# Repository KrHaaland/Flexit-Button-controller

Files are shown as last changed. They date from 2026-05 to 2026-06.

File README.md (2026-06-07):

# Flexit-Button-controller

ESP32-C5 button panel for the **Flexit Tradition-S** ventilation unit. Replaces or parallels the original 5-button control panel with an isolated emulator that adds **Wi-Fi (2.4 GHz + 5 GHz)** and **MQTT** for smart-home integration.

The ESP32-C5 is currently one of the few cheap ESP modules with dual-band Wi-Fi 6, which lets the panel live on either band depending on your home network and signal coverage.

## What it does

The board exposes 5 channels, each mirroring one button + indicator LED on the original Flexit Tradition-S panel:

- **5 button outputs** drive AQY212S solid-state opto-couplers in parallel with on-board tactile switches. A short pulse on a channel looks electrically identical to a finger press, in galvanic isolation from the Flexit unit.
- **5 LED inputs** read the indicator-LED state back from the panel net.

You get three ways to interact with the panel:

1. The physical tactile buttons on the PCB (works without firmware).
2. A self-served web UI (Wi-Fi setup, manual trigger, live LED dots, pulse tuning, MQTT setup).
3. MQTT — subscribe to LED state changes, publish to fire buttons.

## Hardware

- **Module:** ESP32-C5-Mini (USB-C, dual-band Wi-Fi 6, 4 MB flash, no PSRAM)
- **Isolation:** 5x AQY212S solid-state relays (LED-driven MOSFET output, ~3 ms switching)
- **Connector to Flexit:** Micro-MaTch 2x6 (J1), carrying 5 button signals + 5 LED signals + 5 V supply + GND, mating with the cable on the back of the original Flexit panel.
- **PCB:** KiCad files under [`PCB/`](PCB/) (Gerbers/BOM/positions for the fab in [`PCB/production/`](PCB/production/)).

### Pin mapping (set in `FW/ESP32-C5-Flexit/src/main.cpp`)

| Channel | Trigger out | LED in |
|---:|:---:|:---:|
| 1 | IO4 | IO5 |
| 2 | IO3 | IO6 |
| 3 | IO2 | IO7 |
| 4 | IO1 | IO8 |
| 5 | IO0 | IO9 |

Trigger outputs idle LOW and pulse HIGH for ~300 ms (configurable from the UI) to emulate a press. LED inputs are read with `INPUT_PULLDOWN`; the Flexit drives them HIGH when an indicator is lit.

## Build & flash

Requires [PlatformIO](https://platformio.org/) (`pip install platformio` or the VSCode extension).

```bash
cd FW/ESP32-C5-Flexit
pio run                       # compile
pio run -t upload             # flash via USB-C
pio device monitor -b 115200  # serial log
```

The C5 enumerates as `/dev/ttyACM*` (built-in USB Serial JTAG, no driver needed).

## First-time setup

1. Power the ESP32-C5 over USB-C, or via the J1 connector once mounted.
2. With no saved Wi-Fi, the board comes up as an access point:
   - SSID: `Flexit-Setup`
   - Password: `fibonacci` (default; the Wi-Fi form lets you set a custom one if you don't want the documented value).
3. Join that AP and open <http://192.168.4.1/> (also reachable as `http://flexit.local/` via mDNS).
4. In the **Wi-Fi** section, enter your home SSID + password and click *Save & reboot*. You can optionally set a custom AP fallback password in the same form — it persists in NVS. The board joins your network and is then reachable on its STA IP or via `flexit.local`.

Wi-Fi credentials and the AP-password override are stored in NVS and survive a reflash. *Forget & reboot to AP* wipes the Wi-Fi creds but keeps the AP password override.

If the home network is briefly unreachable at boot, the board lands in AP mode but periodically retries (every 5 min) so a transient router outage doesn't strand it.

## Web interface

| Section | What it does |
|---|---|
| **Knapper** | 5 trigger buttons + 5 live LED indicators (polled every 400 ms). |
| **Pulse duration** | Length of the simulated button press (20–2000 ms, default 300 ms). Useful if a Flexit function requires a long-press. |
| **MQTT** | Broker host/port, optional user/password, base topic, heartbeat republish interval, live connection status, MAC-derived client ID. |
| **Wi-Fi** | SSID + password, *Save & reboot* into STA, *Forget* clears creds. Banner at top shows current STA/AP state, RSSI, IP. |

Everything except Wi-Fi changes applies live without reboot.

## MQTT

When the board is in STA mode (joined to your Wi-Fi) and a broker host is configured, it connects to the broker and stays connected with auto-reconnect and a Last Will. With base topic `flexit` (default — configurable in the UI):

| Topic | Direction | Payload | Notes |
|---|---|---|---|
| `flexit/led/1..5/state` | publish | `ON` / `OFF` | Retained. Sent on every transition; also republished periodically if heartbeat > 0. |
| `flexit/sw/1..5/trigger` | subscribe | any (optional `<ms>`) | Any payload triggers a pulse on that channel. A numeric payload overrides the configured pulse duration for that single trigger. |
| `flexit/status` | publish | `online` / `offline` | LWT, retained. |

Client ID is `flexit-<MAC>` (12 hex chars from the chip's eFuse MAC) — globally unique per ESP32. Use it in your broker's ACL.

### Home Assistant example

```yaml
mqtt:
  binary_sensor:
    - name: "Flexit LED 1"
      state_topic: "flexit/led/1/state"
      payload_on: "ON"
      payload_off: "OFF"
    # ... repeat for 2..5
  button:
    - name: "Flexit button 1"
      command_topic: "flexit/sw/1/trigger"
    # ... repeat for 2..5
```

## Firmware updates (OTA)

Once the device is on your Wi-Fi (STA mode), you don't need USB again — there are two ways to push a new build:

### Web upload

1. Build locally: `cd FW/ESP32-C5-Flexit && pio run`. The artifact is `.pio/build/esp32-c5-devkitc1-n4/firmware.bin`.
2. Open the device's web UI (`http://flexit.local/` or its STA IP).
3. Scroll to the **Firmware** section. The current version, build timestamp and free slot space are shown.
4. Pick the new `firmware.bin`, click **Upload & reboot**. The progress bar tracks the upload, then the board reboots into the new image. The page auto-reloads after ~8 s.

### PlatformIO push

```bash
cd FW/ESP32-C5-Flexit
pio run -e esp32-c5-devkitc1-n4-ota -t upload
```

This uses the espota protocol over mDNS at `flexit.local:3232`.

### Partition layout

Switched from the Arduino default (`default.csv`, 1.25 MB per app slot) to `min_spiffs.csv` (1.875 MB per slot, two slots, plus 128 KB SPIFFS). NVS stays at offset `0x9000` so saved Wi-Fi / MQTT / pulse settings survive the migration when you flash the OTA-enabled image for the first time.

### Robustness

The HTTP OTA path is hardened against the common failure modes:

- The 5 button-trigger pins are forced LOW at the start of every upload, and `/trigger` + MQTT-fired triggers are ignored during the upload — a press in flight can't keep the opto-coupler latched through the multi-second multipart parse.
- Idle timeout (10 s) and total timeout (120 s) abort slow-loris uploads.
- A sticky abort flag short-circuits the rest of the upload as soon as `Update.begin`, a short write, or `Update.end` reports an error — no point in streaming 1 MB just to fail at the end.
- MQTT publishes `offline` retained to `<base>/status` and disconnects gracefully before the reboot, so subscribers see the flap immediately instead of waiting out the 30 s keepalive.
- Wi-Fi disconnect + `server.close()` + an 800 ms settle before `ESP.restart()` give the TCP FIN and the HTTP 200 response enough time to flush on a marginal link.
- A Wi-Fi event handler re-binds mDNS and ArduinoOTA whenever the STA interface gets a new IP, so wireless reflash keeps working after a router reboot or AP roam.

### Security model

There's **no authentication** on either OTA path or on the other config endpoints. The assumption is that your Wi-Fi LAN is trusted (this is a home device behind your router, not on the open internet). Anyone with route to the device on TCP 80 or 3232 can re-flash it.

The AP fallback PSK is `fibonacci` by default — yes, the same one this README mentions, on purpose. The Wi-Fi form lets you override it per device if you'd rather not advertise it in the source. Override is persisted in NVS.

If you need stricter controls (HTTP Basic auth on `/update`, an ArduinoOTA password, signed firmware images, broker ACLs, VLANs), open an issue.

## Repo layout

```
.
├── FW/ESP32-C5-Flexit/      PlatformIO project (Arduino framework)
│   ├── src/main.cpp         Firmware
│   └── src/index_html.h     Embedded web UI (single page)
├── PCB/                     KiCad schematic + PCB design
│   └── production/          Gerbers, BOM, positions for fab
└── knappepanel_flexit.kicad_pro
```

## Notes & quirks

- The board has 5 on-board tactile switches in parallel with the opto outputs, and 5 indicator LEDs on the LED nets, so it doubles as a stand-alone bench panel.
- ESP32-C5 boot prints `MSPI Timing: Failed to allocate dummy cacheline for PSRAM memory barrier!` — harmless, the C5-Mini has no PSRAM but the SDK looks for it.
- Verified against a Flexit Tradition-S. Other Flexit models with a different button matrix or LED drive scheme may need pin or polarity changes (see `LED_ACTIVE_HIGH` in `src/main.cpp`).

## License

No license set yet — treat as "all rights reserved" until one is added. Open an issue if you'd like a specific one (MIT / Apache-2.0 / CC-BY-SA for the hardware, etc.).

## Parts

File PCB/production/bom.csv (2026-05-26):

Designator | Footprint | Quantity | Value | LCSC Part #
C1, C2 | 0805 | 2 | 10uF
D1, D2, D3, D4, D5 | 1206 | 5 | LED
J1 | Micromatch_2x6 | 1 | MicroMatch_2x6
R1, R2, R3, R4, R5 | 0805 | 5 | R
SW1, SW2, SW3, SW4, SW5 | Tactile SW 6x6mm | 5 | Tactile SW 6x6mm | C5127964
TP1, TP2 | TestPoint_Pad_1.5x1.5mm | 2 | TestPoint
U1, U2, U3, U4, U5 | AQY212S | 5 | AQY212S
U7 | ESP32-C5Mini | 1 | ~

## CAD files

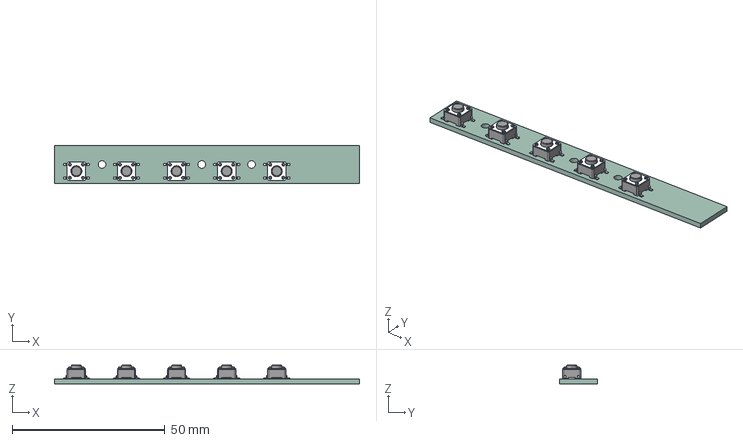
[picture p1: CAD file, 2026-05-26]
.step
100.0 x 12.5 x 6.10 mm
knappepanel_flexit_PCB

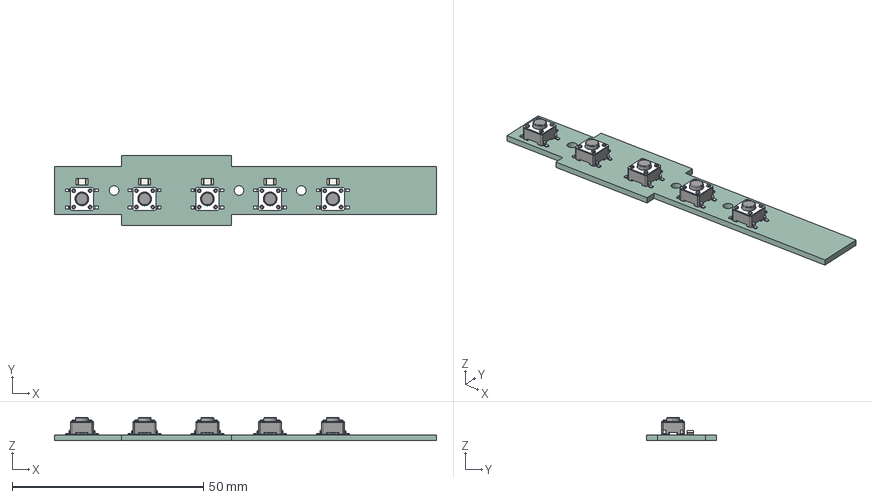
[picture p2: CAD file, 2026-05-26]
PCB/knappepanel.step
100.0 x 18.2 x 6.10 mm
LED_1206_3216Metric x 5
knappepanel_flexit_PCB

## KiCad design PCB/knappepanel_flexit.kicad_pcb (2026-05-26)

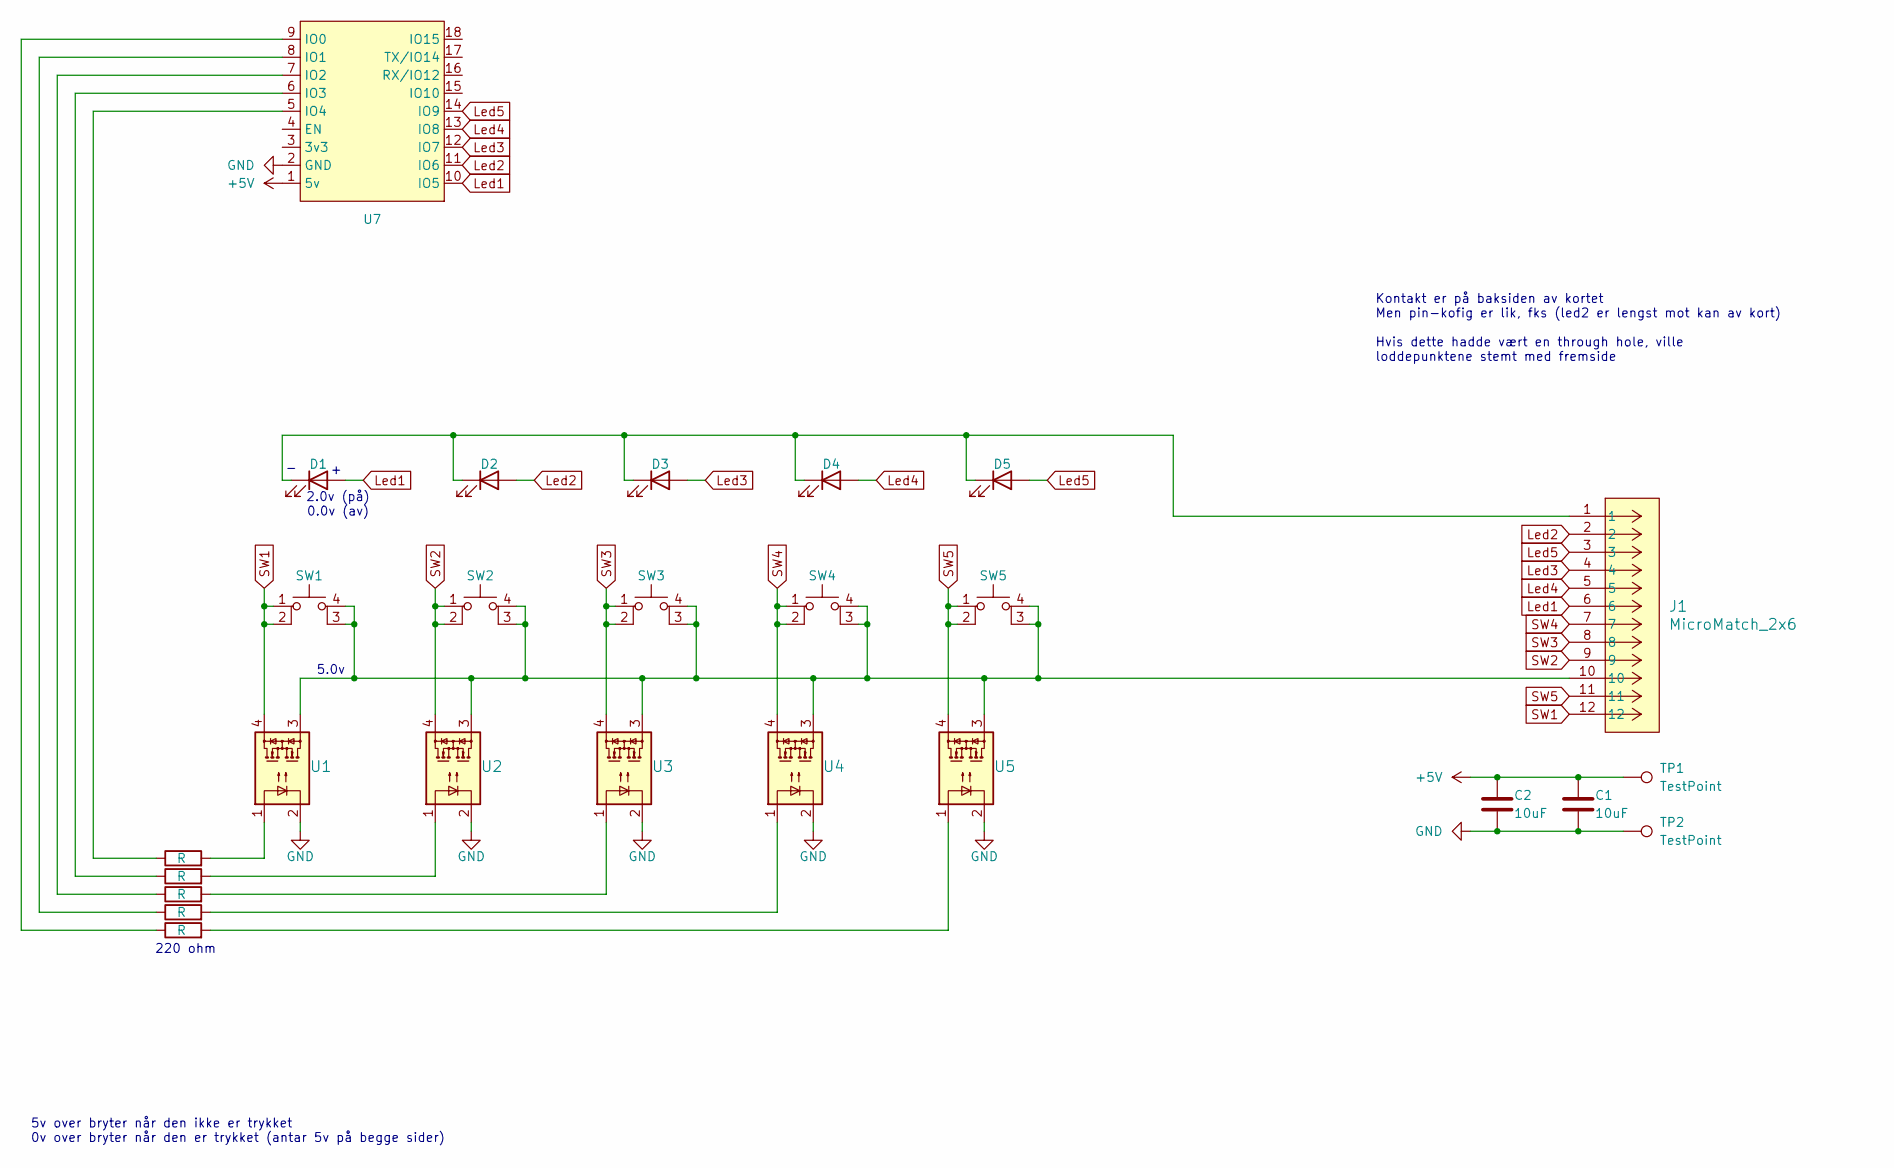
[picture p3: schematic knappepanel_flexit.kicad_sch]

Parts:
C1, C2: 10uF; C_0805_2012Metric
D1, D2, D3, D4, D5: LED; LED_1206_3216Metric
J1: MicroMatch_2x6; Micromatch_2x6
R1, R2, R3, R4, R5: R; R_0805_2012Metric
SW1, SW2, SW3, SW4, SW5: Tactile SW 6x6mm; LCSC Part C5127964
TP1, TP2: TestPoint; TestPoint_Pad_1.5x1.5mm
U1, U2, U3, U4, U5: AQY212S
U7: ESP32-C5Mini

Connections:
+5V: C1.1, C2.1, TP1.1 (1_1), U7.1 (5v)
GND: C1.2, C2.2, TP2.1 (1_1), U1.2, U2.2, U3.2, U4.2, U5.2, U7.2 (GND)
Led1: D1.2 (A), J1.6, U7.10 (IO5)
Led2: D2.2 (A), J1.2, U7.11 (IO6)
Led3: D3.2 (A), J1.4, U7.12 (IO7)
Led4: D4.2 (A), J1.5, U7.13 (IO8)
Led5: D5.2 (A), J1.3, U7.14 (IO9)
unnamed: D1.1 (K), D2.1 (K), D3.1 (K), D4.1 (K), D5.1 (K), J1.1
unnamed: J1.10, SW1.3, SW1.4, SW2.3, SW2.4, SW3.3, SW3.4, SW4.3, SW4.4, SW5.3, SW5.4, U1.3, U2.3, U3.3, U4.3, U5.3
unnamed: R1.2, U1.1
unnamed: R2.2, U2.1
unnamed: R3.2, U3.1
unnamed: R4.2, U4.1
unnamed: R5.2, U5.1
unnamed: R5.1, U7.9 (IO0)
unnamed: R4.1, U7.8 (IO1)
unnamed: R3.1, U7.7 (IO2)
unnamed: R2.1, U7.6 (IO3)
unnamed: R1.1, U7.5 (IO4)
SW1: J1.12, SW1.1, SW1.2, U1.4
SW2: J1.9, SW2.1, SW2.2, U2.4
SW3: J1.8, SW3.1, SW3.2, U3.4
SW4: J1.7, SW4.1, SW4.2, U4.4
SW5: J1.11, SW5.1, SW5.2, U5.4

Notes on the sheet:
5v over bryter når den ikke er trykket 0v over bryter når den er trykket (antar 5v på begge sider)
5.0v
2.0v (på) 0.0v (av)
Kontakt er på baksiden av kortet Men pin-kofig er lik, fks (led2 er lengst mot kan av kort) Hvis dette hadde vært en through hole, ville loddepunktene stemt med fremside
220 ohm

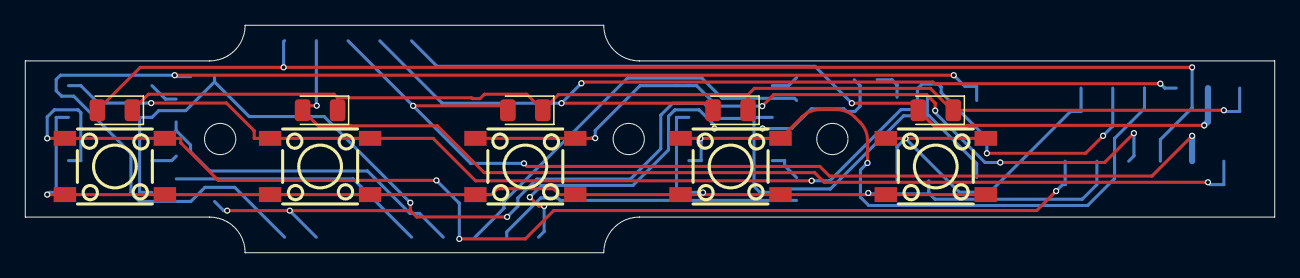
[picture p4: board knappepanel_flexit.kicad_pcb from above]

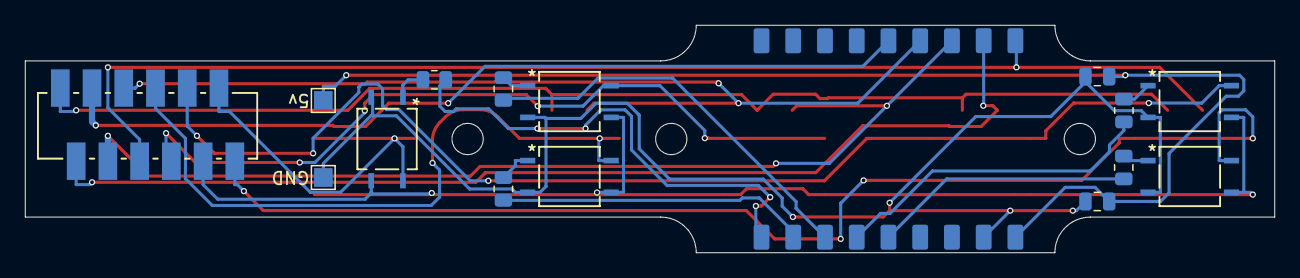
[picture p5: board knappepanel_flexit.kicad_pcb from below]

Board: 2 copper layers, 100.0 x 18.2 mm, 26 parts (16 on the bottom side), 24 nets.

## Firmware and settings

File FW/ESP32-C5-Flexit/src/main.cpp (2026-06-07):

#include <Arduino.h>
#include <WiFi.h>
#include <WebServer.h>
#include <ESPmDNS.h>
#include <Preferences.h>
#include <PubSubClient.h>
#include <Update.h>
#include <ArduinoOTA.h>
#include "index_html.h"

// ---- Firmware identity ----------------------------------------------------
#define FW_VERSION "0.2.1"
#define FW_BUILD   __DATE__ " " __TIME__

// ---- Pin mapping (from KiCad schematic) -----------------------------------
// Optocoupler trigger outputs (drive AQY212S input LEDs through series R):
//   SW1 = IO4, SW2 = IO3, SW3 = IO2, SW4 = IO1, SW5 = IO0
// LED status reads (signals routed from J1 / Flexit panel side):
//   Led1 = IO5, Led2 = IO6, Led3 = IO7, Led4 = IO8, Led5 = IO9
static const uint8_t SW_PINS[5]  = { 4, 3, 2, 1, 0 };
static const uint8_t LED_PINS[5] = { 5, 6, 7, 8, 9 };

// LED polarity: set true if the Flexit drives the line HIGH when the LED is on.
// If your LEDs read inverted, flip this to false.
static constexpr bool LED_ACTIVE_HIGH = true;

// Pulse duration when a button is clicked from the web UI.
// Runtime-tunable via /config and persisted in NVS.
static constexpr uint32_t PULSE_MS_DEFAULT = 300;
static constexpr uint32_t PULSE_MS_MIN = 20;
static constexpr uint32_t PULSE_MS_MAX = 2000;
static uint32_t pulseMs = PULSE_MS_DEFAULT;

// ---- Wi-Fi configuration --------------------------------------------------
// AP fallback (always available when STA fails or no creds stored).
// The AP password is generated per-device on first boot (derived from the MAC),
// stored in NVS, and surfaced on the serial console and the web UI under Wi-Fi.
// The user can override it from the UI. Default no longer ships in the
// public source.
static const char* AP_SSID  = "Flexit-Setup";
static const char* HOSTNAME = "flexit";
static constexpr uint32_t STA_CONNECT_TIMEOUT_MS = 15000;
static String apPassword;  // loaded/generated in setup()

// Periodic STA-retry from AP fallback: if we landed in AP mode at boot (router
// was unreachable), retry STA every STA_RETRY_INTERVAL_MS so a transient outage
// doesn't strand the panel in AP forever.
static constexpr uint32_t STA_RETRY_INTERVAL_MS = 5UL * 60UL * 1000UL;  // 5 min
static uint32_t lastStaRetryAt = 0;

// ---- Globals --------------------------------------------------------------
WebServer server(80);
Preferences prefs;
WiFiClient netClient;
PubSubClient mqtt(netClient);

enum WifiMode : uint8_t { MODE_AP = 0, MODE_STA = 1 };
static WifiMode currentMode = MODE_AP;

// Per-channel pulse end timestamp (millis). 0 = idle.
volatile uint32_t pulseEndAt[5] = { 0, 0, 0, 0, 0 };

// Deferred actions requested from HTTP handlers (executed in loop()).
static volatile bool pendingReboot = false;
static uint32_t rebootAt = 0;

// HTTP OTA bookkeeping.
//   otaActive : true while a multipart /update upload is being processed.
//               Used to suppress button triggers (/trigger and MQTT) so a
//               concurrent press can't keep the opto latched through the upload.
//   otaAborted: sticky abort flag set the moment Update reports an error so
//               subsequent chunks short-circuit and we surface the error early.
static volatile bool otaActive  = false;
static bool          otaAborted = false;
static uint32_t      otaStartMs = 0;
static uint32_t      otaLastByteMs = 0;
static constexpr uint32_t OTA_IDLE_TIMEOUT_MS  = 10000;   // 10 s without bytes -> abort
static constexpr uint32_t OTA_TOTAL_TIMEOUT_MS = 120000;  // 120 s total upload cap

// ---- MQTT state -----------------------------------------------------------
static String mqttHost;
static uint16_t mqttPort = 1883;
static String mqttUser;
static String mqttPass;
static String mqttBase = "flexit";
static bool ledLastPub[5] = { false, false, false, false, false };
static bool ledStateInit = false;
static uint32_t mqttLastTry = 0;
static int mqttLastState = 0;  // PubSubClient state for diagnostics
static constexpr uint32_t MQTT_RETRY_MS = 5000;

// Periodic republish of LED state (in addition to on-change publishes).
// 0 disables the heartbeat — only transitions are published.
static constexpr uint16_t PUB_INTERVAL_MAX_SEC = 3600;
static uint16_t mqttPubIntervalSec = 0;
static uint32_t mqttLastPubAt = 0;

static inline bool readLed(uint8_t idx) {
  int v = digitalRead(LED_PINS[idx]);
  return LED_ACTIVE_HIGH ? (v == HIGH) : (v == LOW);
}

static void startPulse(uint8_t idx) {
  digitalWrite(SW_PINS[idx], HIGH);
  pulseEndAt[idx] = millis() + pulseMs;
}

static void servicePulses() {
  uint32_t now = millis();
  for (uint8_t i = 0; i < 5; i++) {
    if (pulseEndAt[i] != 0 && (int32_t)(now - pulseEndAt[i]) >= 0) {
      digitalWrite(SW_PINS[i], LOW);
      pulseEndAt[i] = 0;
    }
  }
}

// Forcefully drop every in-flight pulse. Called when a long blocking op
// (HTTP OTA upload, ArduinoOTA) is about to take over the main loop and
// servicePulses() won't run again until reboot.
static void clearPulsesNow() {
  for (uint8_t i = 0; i < 5; i++) {
    digitalWrite(SW_PINS[i], LOW);
    pulseEndAt[i] = 0;
  }
}

// ---- JSON helpers ---------------------------------------------------------
static String jsonEscape(const String& s) {
  String out;
  out.reserve(s.length() + 2);
  for (size_t i = 0; i < s.length(); i++) {
    char c = s[i];
    switch (c) {
      case '"':  out += "\\\""; break;
      case '\\': out += "\\\\"; break;
      case '\b': out += "\\b";  break;
      case '\f': out += "\\f";  break;
      case '\n': out += "\\n";  break;
      case '\r': out += "\\r";  break;
      case '\t': out += "\\t";  break;
      default:
        if ((uint8_t)c < 0x20) {
          char buf[8];
          snprintf(buf, sizeof(buf), "\\u%04x", c);
          out += buf;
        } else {
          out += c;
        }
    }
  }
  return out;
}

// ---- MQTT -----------------------------------------------------------------
// Topic layout (with base = "flexit"):
//   flexit/led/<1..5>/state    -- published, retained: "ON" | "OFF"
//   flexit/sw/<1..5>/trigger   -- subscribed, any payload triggers a pulse
//                                 (or payload "<ms>" overrides pulseMs)
//   flexit/status              -- LWT, retained: "online" | "offline"

static String mqttClientId() {
  // Use the full 48-bit base MAC so the ID is unique per device.
  uint64_t mac = ESP.getEfuseMac();
  char buf[24];
  snprintf(buf, sizeof(buf), "flexit-%012llx",
           (unsigned long long)(mac & 0xFFFFFFFFFFFFULL));
  return String(buf);
}

static void mqttCallback(char* topic, byte* payload, unsigned int len) {
  // Ignore triggers while an OTA upload is being processed — a press now
  // would latch through the long-blocking upload.
  if (otaActive) {
    Serial.println("[mqtt] trigger ignored: ota in progress");
    return;
  }
  // Expect: <base>/sw/<n>/trigger
  String t(topic);
  String prefix = mqttBase + "/sw/";
  if (!t.startsWith(prefix)) return;
  int slash = t.indexOf('/', prefix.length());
  if (slash < 0) return;
  if (t.substring(slash) != "/trigger") return;
  int n = t.substring(prefix.length(), slash).toInt();
  if (n < 1 || n > 5) return;

  // Optional payload: "<ms>" to override the pulse duration for this trigger.
  String p;
  p.reserve(len);
  for (unsigned int i = 0; i < len; i++) p += (char)payload[i];
  p.trim();

  uint32_t saved = pulseMs;
  if (!p.isEmpty()) {
    long v = p.toInt();
    if (v >= (long)PULSE_MS_MIN && v <= (long)PULSE_MS_MAX) {
      pulseMs = (uint32_t)v;
    }
  }
  Serial.printf("[mqtt] trigger sw=%d (pulse %u ms)\n", n, (unsigned)pulseMs);
  startPulse((uint8_t)(n - 1));
  pulseMs = saved;
}

static void mqttPublishLed(uint8_t i, bool on, bool retained = true) {
  String topic = mqttBase + "/led/" + String(i + 1) + "/state";
  mqtt.publish(topic.c_str(), on ? "ON" : "OFF", retained);
}

static void mqttReconnect() {
  if (currentMode != MODE_STA) return;
  if (mqttHost.isEmpty()) return;
  if (mqtt.connected()) return;
  uint32_t now = millis();
  if (mqttLastTry != 0 && (now - mqttLastTry) < MQTT_RETRY_MS) return;
  mqttLastTry = now;

  mqtt.setServer(mqttHost.c_str(), mqttPort);
  mqtt.setKeepAlive(30);
  mqtt.setBufferSize(512);
  mqtt.setCallback(mqttCallback);

  String cid = mqttClientId();
  String willTopic = mqttBase + "/status";

  Serial.printf("[mqtt] connecting to %s:%u as %s\n",
                mqttHost.c_str(), mqttPort, cid.c_str());

  bool ok;
  if (mqttUser.isEmpty()) {
    ok = mqtt.connect(cid.c_str(), nullptr, nullptr,
                      willTopic.c_str(), 1, true, "offline");
  } else {
    ok = mqtt.connect(cid.c_str(), mqttUser.c_str(), mqttPass.c_str(),
                      willTopic.c_str(), 1, true, "offline");
  }

  mqttLastState = mqtt.state();
  if (!ok) {
    Serial.printf("[mqtt] connect failed, state=%d\n", mqttLastState);
    return;
  }
  Serial.println("[mqtt] connected");
  mqtt.publish(willTopic.c_str(), "online", true);

  String subTopic = mqttBase + "/sw/+/trigger";
  mqtt.subscribe(subTopic.c_str());
  Serial.printf("[mqtt] subscribed %s\n", subTopic.c_str());

  // Publish current LED states (retained) on (re)connect.
  for (uint8_t i = 0; i < 5; i++) {
    bool on = readLed(i);
    mqttPublishLed(i, on, true);
    ledLastPub[i] = on;
  }
  ledStateInit = true;
}

static void mqttPublishChanges() {
  if (!mqtt.connected()) return;
  uint32_t now = millis();
  bool heartbeatDue = (mqttPubIntervalSec > 0) &&
                      ((now - mqttLastPubAt) >= (uint32_t)mqttPubIntervalSec * 1000UL);
  for (uint8_t i = 0; i < 5; i++) {
    bool on = readLed(i);
    if (!ledStateInit || on != ledLastPub[i] || heartbeatDue) {
      mqttPublishLed(i, on, true);
      ledLastPub[i] = on;
    }
  }
  if (heartbeatDue || !ledStateInit) mqttLastPubAt = now;
  ledStateInit = true;
}

static void mqttApplyConfig() {
  // Called after settings change. Drop existing connection so reconnect
  // picks up the new server/credentials.
  if (mqtt.connected()) {
    String willTopic = mqttBase + "/status";
    mqtt.publish(willTopic.c_str(), "offline", true);
    mqtt.disconnect();
  }
  mqttLastTry = 0;  // try again immediately
  ledStateInit = false;
}

// Publish a graceful 'offline' on the status topic and tear down the MQTT
// session so subscribers see an immediate state change rather than waiting
// for the broker's keepalive (30 s) to expire after the device reboots.
// Safe to call when MQTT is disabled or not connected — it's a no-op.
static void mqttPublishOfflineAndDisconnect() {
  if (!mqtt.connected()) return;
  String willTopic = mqttBase + "/status";
  mqtt.publish(willTopic.c_str(), "offline", true);
  mqtt.loop();         // flush the publish over the wire
  mqtt.disconnect();
  netClient.stop();    // close the underlying TCP socket
}

// ---- HTTP handlers --------------------------------------------------------
static void handleRoot() {
  server.send_P(200, "text/html; charset=utf-8", INDEX_HTML);
}

static void handleStatus() {
  String body;
  body.reserve(96);
  body += F("{\"leds\":[");
  for (uint8_t i = 0; i < 5; i++) {
    body += readLed(i) ? '1' : '0';
    if (i < 4) body += ',';
  }
  body += F("],\"pulses\":[");
  uint32_t now = millis();
  for (uint8_t i = 0; i < 5; i++) {
    bool active = (pulseEndAt[i] != 0) && ((int32_t)(now - pulseEndAt[i]) < 0);
    body += active ? '1' : '0';
    if (i < 4) body += ',';
  }
  body += F("]}");
  server.sendHeader("Cache-Control", "no-store");
  server.send(200, "application/json", body);
}

static void handleNetinfo() {
  String savedSsid = prefs.getString("ssid", "");
  String body;
  body.reserve(224);
  body += F("{\"mode\":\"");
  body += (currentMode == MODE_STA ? "STA" : "AP");
  body += F("\",\"ssid\":\"");
  if (currentMode == MODE_STA) {
    body += jsonEscape(WiFi.SSID());
  } else {
    body += jsonEscape(String(AP_SSID));
  }
  body += F("\",\"ip\":\"");
  body += (currentMode == MODE_STA
           ? WiFi.localIP().toString()
           : WiFi.softAPIP().toString());
  body += F("\",\"rssi\":");
  body += (currentMode == MODE_STA ? String(WiFi.RSSI()) : String(0));
  body += F(",\"savedSsid\":\"");
  body += jsonEscape(savedSsid);
  // Surface the AP password so the user can see / copy it from a phone that
  // has joined the setup AP. Only included when currently in AP mode — when
  // joined to the home network we don't echo it.
  body += F("\",\"apSsid\":\"");
  body += jsonEscape(String(AP_SSID));
  if (currentMode == MODE_AP) {
    body += F("\",\"apPass\":\"");
    body += jsonEscape(apPassword);
  }
  body += F("\"}");
  server.sendHeader("Cache-Control", "no-store");
  server.send(200, "application/json", body);
}

static void handleTrigger() {
  if (otaActive) {
    server.send(503, "application/json",
                "{\"ok\":false,\"error\":\"ota in progress\"}");
    return;
  }
  if (!server.hasArg("sw")) {
    server.send(400, "text/plain", "missing sw");
    return;
  }
  int sw = server.arg("sw").toInt();
  if (sw < 1 || sw > 5) {
    server.send(400, "text/plain", "sw out of range");
    return;
  }
  startPulse((uint8_t)(sw - 1));
  server.send(200, "application/json", "{\"ok\":true}");
}

static void handleConfigGet() {
  String body;
  body.reserve(48);
  body += F("{\"pulseMs\":");
  body += pulseMs;
  body += F(",\"min\":");
  body += PULSE_MS_MIN;
  body += F(",\"max\":");
  body += PULSE_MS_MAX;
  body += F("}");
  server.sendHeader("Cache-Control", "no-store");
  server.send(200, "application/json", body);
}

static void handleConfigSet() {
  if (!server.hasArg("pulseMs")) {
    server.send(400, "text/plain", "missing pulseMs");
    return;
  }
  long v = server.arg("pulseMs").toInt();
  if (v < (long)PULSE_MS_MIN || v > (long)PULSE_MS_MAX) {
    server.send(400, "text/plain", "pulseMs out of range");
    return;
  }
  pulseMs = (uint32_t)v;
  prefs.putULong("pulse_ms", pulseMs);
  Serial.printf("[cfg] pulse_ms = %u\n", (unsigned)pulseMs);
  server.send(200, "application/json", "{\"ok\":true}");
}

static const char* mqttStateStr(int s) {
  switch (s) {
    case -4: return "timeout";
    case -3: return "lost";
    case -2: return "failed";
    case -1: return "disconnected";
    case 0:  return "connected";
    case 1:  return "bad-protocol";
    case 2:  return "bad-client-id";
    case 3:  return "unavailable";
    case 4:  return "bad-credentials";
    case 5:  return "unauthorized";
    default: return "unknown";
  }
}

static void handleMqttGet() {
  bool connected = mqtt.connected();
  int state = connected ? 0 : mqttLastState;
  String body;
  body.reserve(256);
  body += F("{\"host\":\"");   body += jsonEscape(mqttHost);
  body += F("\",\"port\":");   body += mqttPort;
  body += F(",\"user\":\"");   body += jsonEscape(mqttUser);
  body += F("\",\"base\":\"");  body += jsonEscape(mqttBase);
  body += F("\",\"pubIntervalSec\":"); body += mqttPubIntervalSec;
  body += F(",\"pubIntervalMax\":"); body += PUB_INTERVAL_MAX_SEC;
  body += F(",\"connected\":"); body += (connected ? "true" : "false");
  body += F(",\"state\":\""); body += mqttStateStr(state);
  body += F("\",\"clientId\":\""); body += jsonEscape(mqttClientId());
  body += F("\",\"enabled\":"); body += (mqttHost.isEmpty() ? "false" : "true");
  body += F("}");
  server.sendHeader("Cache-Control", "no-store");
  server.send(200, "application/json", body);
}

static void handleMqttSet() {
  // host="" disables MQTT.
  String host = server.hasArg("host") ? server.arg("host") : String("");
  long port   = server.hasArg("port") ? server.arg("port").toInt() : 1883;
  String user = server.hasArg("user") ? server.arg("user") : String("");
  String pass = server.hasArg("pass") ? server.arg("pass") : String("");
  String base = server.hasArg("base") ? server.arg("base") : String("flexit");
  host.trim(); user.trim(); base.trim();

  if (port < 1 || port > 65535) {
    server.send(400, "text/plain", "port out of range");
    return;
  }
  if (host.length() > 64 || user.length() > 64 || pass.length() > 64 ||
      base.length() > 32 || base.isEmpty()) {
    server.send(400, "text/plain", "field length out of range");
    return;
  }
  // Disallow leading/trailing slashes in base.
  while (base.startsWith("/")) base.remove(0, 1);
  while (base.endsWith("/"))   base.remove(base.length() - 1);
  if (base.isEmpty()) base = "flexit";

  long pubInterval = server.hasArg("pubIntervalSec")
                        ? server.arg("pubIntervalSec").toInt()
                        : (long)mqttPubIntervalSec;
  if (pubInterval < 0 || pubInterval > (long)PUB_INTERVAL_MAX_SEC) {
    server.send(400, "text/plain", "pubIntervalSec out of range");
    return;
  }

  prefs.putString("mq_host", host);
  prefs.putUShort("mq_port", (uint16_t)port);
  prefs.putString("mq_user", user);
  prefs.putString("mq_pass", pass);
  prefs.putString("mq_base", base);
  prefs.putUShort("mq_pubint", (uint16_t)pubInterval);

  mqttHost = host;
  mqttPort = (uint16_t)port;
  mqttUser = user;
  mqttPass = pass;
  mqttBase = base;
  mqttPubIntervalSec = (uint16_t)pubInterval;
  mqttLastPubAt = millis();  // reset heartbeat phase

  Serial.printf("[mqtt] saved host=%s port=%u base=%s user=%s\n",
                mqttHost.c_str(), mqttPort, mqttBase.c_str(),
                mqttUser.isEmpty() ? "(none)" : mqttUser.c_str());

  mqttApplyConfig();
  server.send(200, "application/json", "{\"ok\":true}");
}

static void handleWifiSave() {
  if (!server.hasArg("ssid")) {
    server.send(400, "text/plain", "missing ssid");
    return;
  }
  String ssid = server.arg("ssid");
  String pass = server.hasArg("pass") ? server.arg("pass") : String("");
  ssid.trim();
  if (ssid.isEmpty() || ssid.length() > 32) {
    server.send(400, "text/plain", "ssid empty or too long");
    return;
  }
  if (pass.length() > 64) {
    server.send(400, "text/plain", "pass too long");
    return;
  }
  // Validate every field BEFORE we touch NVS — otherwise an invalid apPass
  // would land us with the new ssid/pass already persisted but the response
  // reporting failure (a real footgun for the user).
  String apPass;
  if (server.hasArg("apPass")) {
    apPass = server.arg("apPass");
    apPass.trim();
    if (!apPass.isEmpty() && (apPass.length() < 8 || apPass.length() > 63)) {
      server.send(400, "text/plain", "apPass must be 8..63 chars (WPA2)");
      return;
    }
  }

  // All validated; commit atomically-ish (NVS doesn't have transactions, but
  // these three writes share the same call site and execute back-to-back).
  prefs.putString("ssid", ssid);
  prefs.putString("pass", pass);
  if (!apPass.isEmpty()) {
    prefs.putString("ap_pass", apPass);
    apPassword = apPass;
    Serial.println("[wifi] AP password updated");
  }
  Serial.printf("[wifi] new credentials saved: ssid=\"%s\"\n", ssid.c_str());
  server.send(200, "application/json", "{\"ok\":true,\"reboot\":true}");
  mqttPublishOfflineAndDisconnect();
  rebootAt = millis() + 800;
  pendingReboot = true;
}

static void handleWifiClear() {
  prefs.remove("ssid");
  prefs.remove("pass");
  Serial.println("[wifi] credentials cleared");
  server.send(200, "application/json", "{\"ok\":true,\"reboot\":true}");
  mqttPublishOfflineAndDisconnect();
  rebootAt = millis() + 800;
  pendingReboot = true;
}

static void handleVersionGet() {
  String body;
  body.reserve(192);
  body += F("{\"version\":\"");   body += FW_VERSION;
  body += F("\",\"build\":\"");   body += FW_BUILD;
  body += F("\",\"sdk\":\"");     body += ESP.getSdkVersion();
  body += F("\",\"chip\":\"");    body += ESP.getChipModel();
  body += F("\",\"flashSize\":"); body += ESP.getFlashChipSize();
  body += F(",\"freeHeap\":");    body += ESP.getFreeHeap();
  body += F(",\"sketchSize\":");  body += ESP.getSketchSize();
  body += F(",\"freeSketch\":");  body += ESP.getFreeSketchSpace();
  body += F("}");
  server.sendHeader("Cache-Control", "no-store");
  server.send(200, "application/json", body);
}
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
void loop() {
  server.handleClient();
  servicePulses();

  if (currentMode == MODE_STA) {
    ArduinoOTA.handle();
  }

  mqttReconnect();
  if (mqtt.connected()) {
    mqtt.loop();
    mqttPublishChanges();
  }

  // Periodic STA retry from AP fallback: if we landed in AP at boot because
  // the router was unreachable, retry STA every STA_RETRY_INTERVAL_MS so a
  // transient outage doesn't strand the device on the setup AP forever.
  // Suppress while OTA is active (we don't want to drop Wi-Fi during a flash).
  if (currentMode == MODE_AP && !otaActive &&
      (millis() - lastStaRetryAt) > STA_RETRY_INTERVAL_MS) {
    lastStaRetryAt = millis();
    String savedSsid = prefs.getString("ssid", "");
    String savedPass = prefs.getString("pass", "");
    if (!savedSsid.isEmpty()) {
      Serial.println("[wifi] periodic STA retry from AP fallback...");
      WiFi.softAPdisconnect(true);
      if (connectSTA(savedSsid, savedPass)) {
        currentMode = MODE_STA;
        // mDNS + ArduinoOTA come back up via wifiEventHandler on STA_GOT_IP.
      } else {
        // STA still down — return to AP mode.
        startAP();
      }
    }
  }

  if (pendingReboot && (int32_t)(millis() - rebootAt) >= 0) {
    Serial.println("[sys] rebooting");
    // Clean teardown so a slow-Wi-Fi response gets flushed before reset.
    server.close();
    WiFi.disconnect(true, false);
    delay(150);
    ESP.restart();
  }
}

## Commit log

2026-05-26 Initial import
    ESP32-C5 firmware for the Flexit knappepanel:
    - 5 button-trigger outputs through AQY212S optocouplers (configurable pulse)
    - 5 LED status inputs
    - Web UI with Wi-Fi STA/AP fallback configuration
    - MQTT client: configurable broker, base topic, heartbeat republish interval,
    LWT, MAC-derived client ID, on-change + periodic LED state publishes
    KiCad schematic and PCB included.
    [.step, bom.csv, designators.csv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]
2026-05-26 Add README
    Overview, hardware pin mapping, build/flash steps, first-time AP setup,
    web UI tour, MQTT topic reference with a Home Assistant snippet, and
    repo layout.
2026-06-07 Add wireless firmware updates (OTA) with web upload + ArduinoOTA push
    - Partition switch from default.csv (1.25 MB/slot) to min_spiffs.csv
    (1.875 MB/slot, two slots). NVS stays at 0x9000 so saved Wi-Fi/MQTT/
    pulse settings survive the migration.
    - HTTP OTA at POST /update with web-based progress UI: file size pre-check
    against ESP.getFreeSketchSpace, multipart upload, percent + bytes + rate
    display, Cancel button, post-flash /version polling with manual reload
    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
2026-06-07 Revert AP fallback PSK to "fibonacci" with one-time NVS migration
    The per-device MAC-derived default introduced in the previous commit was
    overkill for a residential LAN device. Going back to the documented PSK
    "fibonacci" by default. The user-override mechanism (set a custom AP
    password in the Wi-Fi form, persisted in NVS) is unchanged.
    To migrate devices already running the previous firmware (which generated
    and persisted a random per-device PSK on first boot), a one-shot NVS
    schema version is read on boot:
    - "ap_pass_v" absent or < 2 -> overwrite "ap_pass" with "fibonacci",
    write "ap_pass_v" = 2.
    - "ap_pass_v" >= 2 -> no-op; user-set o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
    [main.cpp]
2026-06-07 Bump FW_VERSION to 0.2.1 (OTA validation on battery power)
    Pure version bump used to verify the OTA path against a USB-disconnected,
    powerbank-driven board:
    pre-OTA : /version = 0.2.0 / build 20:18:03
    post-OTA : /version = 0.2.1 / build 20:24:08
    same : IP, SSID, MQTT session, MAC-derived client ID, pulse_ms = 50
    duration : ~14 s upload + ~6 s reboot = ~20 s end-to-end
    network : mDNS resolved flexit.local; espota uploaded over Wi-Fi
    smoke : POST /trigger?sw=1 -> pulses[0]=1 then 0 after 50 ms
    No code-behaviour change beyond the version string.
    [main.cpp]
